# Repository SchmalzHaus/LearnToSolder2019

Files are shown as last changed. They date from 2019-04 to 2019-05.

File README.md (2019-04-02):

# LearnToSolder2018

UNDER CONSTRUCTION - BEING UPDATED

Learn To Solder 2017 Board, assembled

## Introduction

For the past couple years, Deanna Schmalz has designed a simple circuit board which we then use to teach learn to solder classes. We  make enough boards and buy enough parts to teach all of the 4th graders at Glen Lake Elementary School in Minnetonka Minnesota, USA how to solder.

This site contains all of the information related to this year's Learn To Solder board. If you want to learn more about how to solder, if you want to know what you need to purchase so you can solder at home, or if you want to make more of these boards for yourself or your organization, this site has everything you'll need.

If you want to reach Brian Schmalz (brian@schmalzaus.com) or Deanna (deanna@schmalzhaus.com) to ask us any questions, please do so. 

All text files and designs on this site are Open Source. You are free to use these files and do whatever you wish with them.

Bare Board, back and front

## LearnToSolder 2017 Kit Contents

* Qty 1 Bare Circuit Board (see above image for back and front views of the bare board)
* Qty 2 Switches
* Qty 2 Blinking LEDs
* Qty 1 Battery Holder
* Qty 1 Battery

## Tools

To solder electronic kits together, you will need (at a minimum)

### Soldering Iron

We do not recommend buying a soldering iron unless it is 'temperature controlled'. This means you get to set the tip temperature with a knob or buttons, and the iron will only heat up as much as it needs to in order to maintain that temperature. Using a non-temp controlled iron has, in our experience, led to lots of frustration and failed kits.

This is the iron we recommend, as we've had great experience with it and it is very inexpensive : [http://www.hobbyking.com/hobbyking/store/__19240__Soldering_Station_with_Adjustable_Heat_Range_US_Warehouse_.html]

You can also by this same type of iron from many other places, including Amazon and Ebay, but the price tends to be a bit higher. Some of the companies listed below under Other Soldering Kits also sell tools like irons.

### Solder

For beginners, we strongly recommend using leaded solder (rather than lead-free). The safety risk is very minimal (just be sure to wash your hands with soap when you are done) and it is far, far easier to get good soldered joints with leaded solder when you're just starting to learn soldering. You can buy leaded electronic solder at many on-line stores like SparkFun [https://www.sparkfun.com/products/9161] or Adafruit [https://www.adafruit.com/products/1886]. Make sure to buy 60/40 or 63/37 (those numbers represent the ratio of tin to lead in the solder) electronic solder - there are other solders out there (like silver solder for jewelry for example) that won't work for electronics.

### Brass Sponge

When you buy your iron, buy a bras sponge if the iron doesn't already come with it. These are much better than the watter sponge that comes with the iron for cleaning the tip of the soldering iron.

### Wire Cutter

All of the companies listed below sell small wire cutters, or you can get them locally at hardware stores too. The best kind is something that will allow you to cut off wires flush with the board - sometimes called 'flush cutters'. For example [https://www.sparkfun.com/products/11952] or [https://www.adafruit.com/products/152]

### Other tools

There are lots of other tools you can get to help you while solder. Third-hands can be very useful. Needle nose pliers, solder suckers, magnifying glasses, solder wick, wire strippers, etc.

## Kit Assembly Process (overview)

There are only a couple steps to assembling this kit, as it is very simple. If you have done soldering before, you can just walk through this overview of the steps to complete your kit. If you want to learn more about how to do the actual soldering of a joint, the following websites and resources will give you plenty of background materials and explanations:

https://learn.sparkfun.com/tutorials/how-to-solder---through-hole-soldering

http://www.howtogeek.com/63630/how-to-use-a-soldering-iron-a-beginners-guide/

https://cdn-learn.adafruit.com/downloads/pdf/adafruit-guide-excellent-soldering.pdf

### Steps:

1. Insert the two switches into the board. Make sure all parts go into the board from the top side (with the thick white lines) to the back side (with all of the text). The switches snap down into the board - you sometimes have to press them in hard to get them to snap. Solder the four pins of each switch.

2. Insert the two LEDs. Long wires go into square holes. You sometimes have to wiggle the LEDs a bit to get them to press all the way flat down on the top side of the board due to a thick spot on the LED leads. Bend the leads apart on the back side to keep the LEDs in place as you solder the LED wires on the back side of the board.

3. Insert the battery holder to the front of the board, being careful to align the outline of the battery hold to the white outline on the top of the board (there is a square tab on the battery holder than needs to match up to the square tab part of the outline). While holding the battery holder into the board, flip it over and solder both pins.

4. Insert the battery into the holder, flat shiny side up. Press the buttons to see your LEDs light. If you hold down a button, it's LED will begin to cycle through different colors and begin to blink.

You can follow the path of the electricity by looking at the thick white line on the top side of the board, or the thinner copper wires on the back side of the board. (They mirror each other.) 

## Other Soldering Kits

There are SO MANY kits available today, it's impossible to list all of them, or even the good ones. If you do a Google search for "electronic soldering kit" you will find lots of them out there. Some are easier than others, and some come with great instructions (and some don't).

We buy a lot of high quality soldering kits from the following on-line companies:

Evil Mad Scientist [http://shop.evilmadscientist.com/]
* Their Boldport Buggy is excellent [http://shop.evilmadscientist.com/]
* The Flickery Flame is a great beginner kit [http://shop.evilmadscientist.com/productsmenu/793]

Spark Fun Electronics [https://www.sparkfun.com/]
* They have a whole catagory of 'kits', some of which are soldering kits [https://www.sparkfun.com/categories/157]
* The SparkFun Simon Says - Through-Hole kit is really fun [https://www.sparkfun.com/products/10547]

Adafruit [https://www.adafruit.com/]
* The Drawdio is quite fun [https://www.adafruit.com/categories/28]
* Their Minty Boost is actually quite useful [https://www.adafruit.com/products/14]

SeeedStudio [http://www.seeedstudio.com/]
* Their 4-Soldering Zoo Kit looks super cute [https://www.seeedstudio.com/item_detail.html?p_id=1950]

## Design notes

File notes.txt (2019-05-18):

LearnToSolder 2019 Notes file

Build of first rev (v1) of board:
* Thermals too aggressive. Use traces on just one layer instead. (Done)
* Update LED footprint
  - Same sized pads on both top and bottom layers (Done)
  - Separate pads from each other for fewer solder bridges (Done)
* Create cutout for pin 1 dot for processor on tSilk somehow? (Done)
* Update silk on back 
  - larger/thicker text in general (Done)
  - Better build hints (line drawings of LED long lead and battery holder shape) (Done)
* Possibly update silk on front - "Glen Lake"? (Done)

(5/18/2019) V2 of the board was made with all of the above fixed
Blue solder mask

Things to improve for 2020:
* Do not use a ground plane. JLCPCB does not have good enough registration between the solder mask and the copper, so when kids use too much solder, it makes bridges between pins and GND.
* Do not pass out the pliers. They are not needed, and confuse the students.
* Use the document camera to live-demo soldering on the exact board they will solder on. Replace the microscope soldering video witht this.

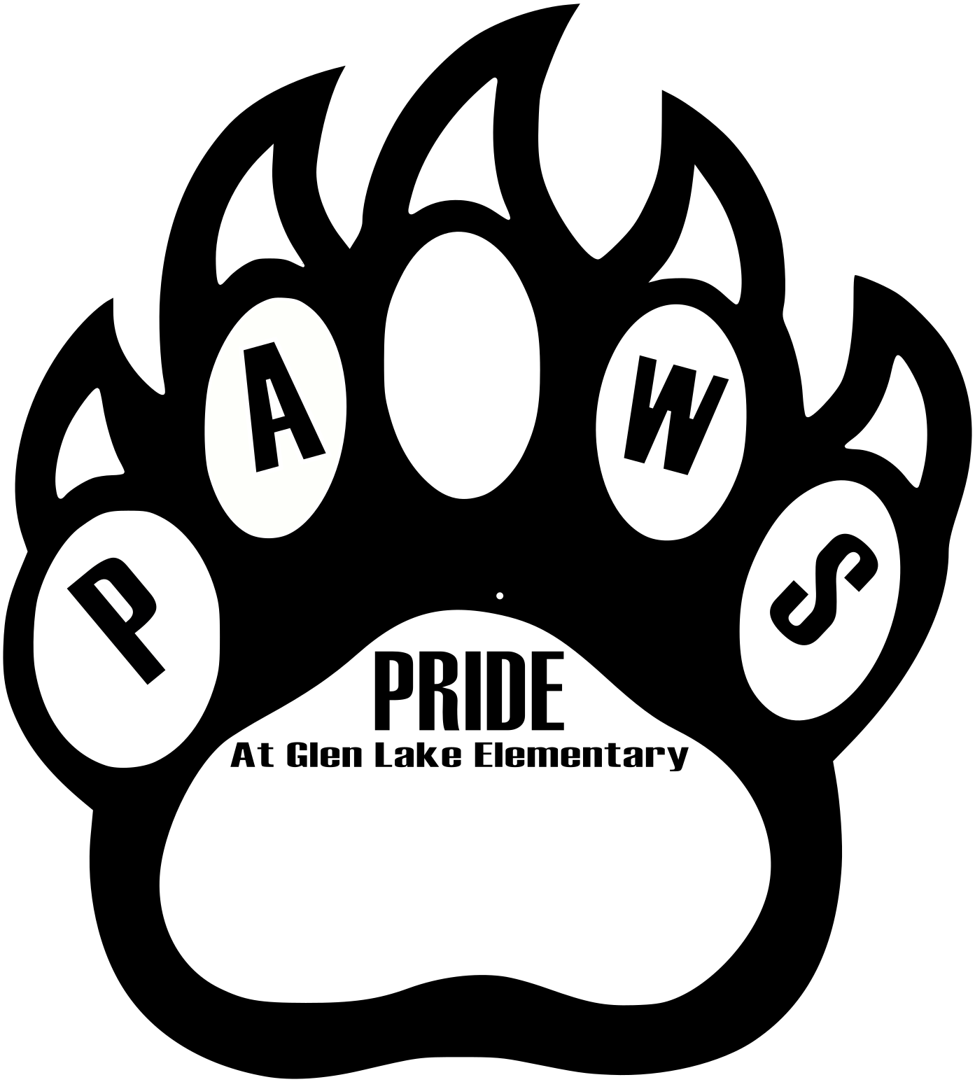
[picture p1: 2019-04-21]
pics/bear-paw-clipart.png

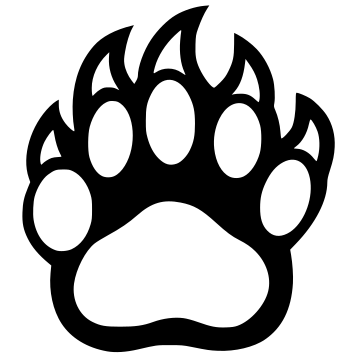
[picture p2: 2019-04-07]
pics/bear-paw-clipart.hi.png

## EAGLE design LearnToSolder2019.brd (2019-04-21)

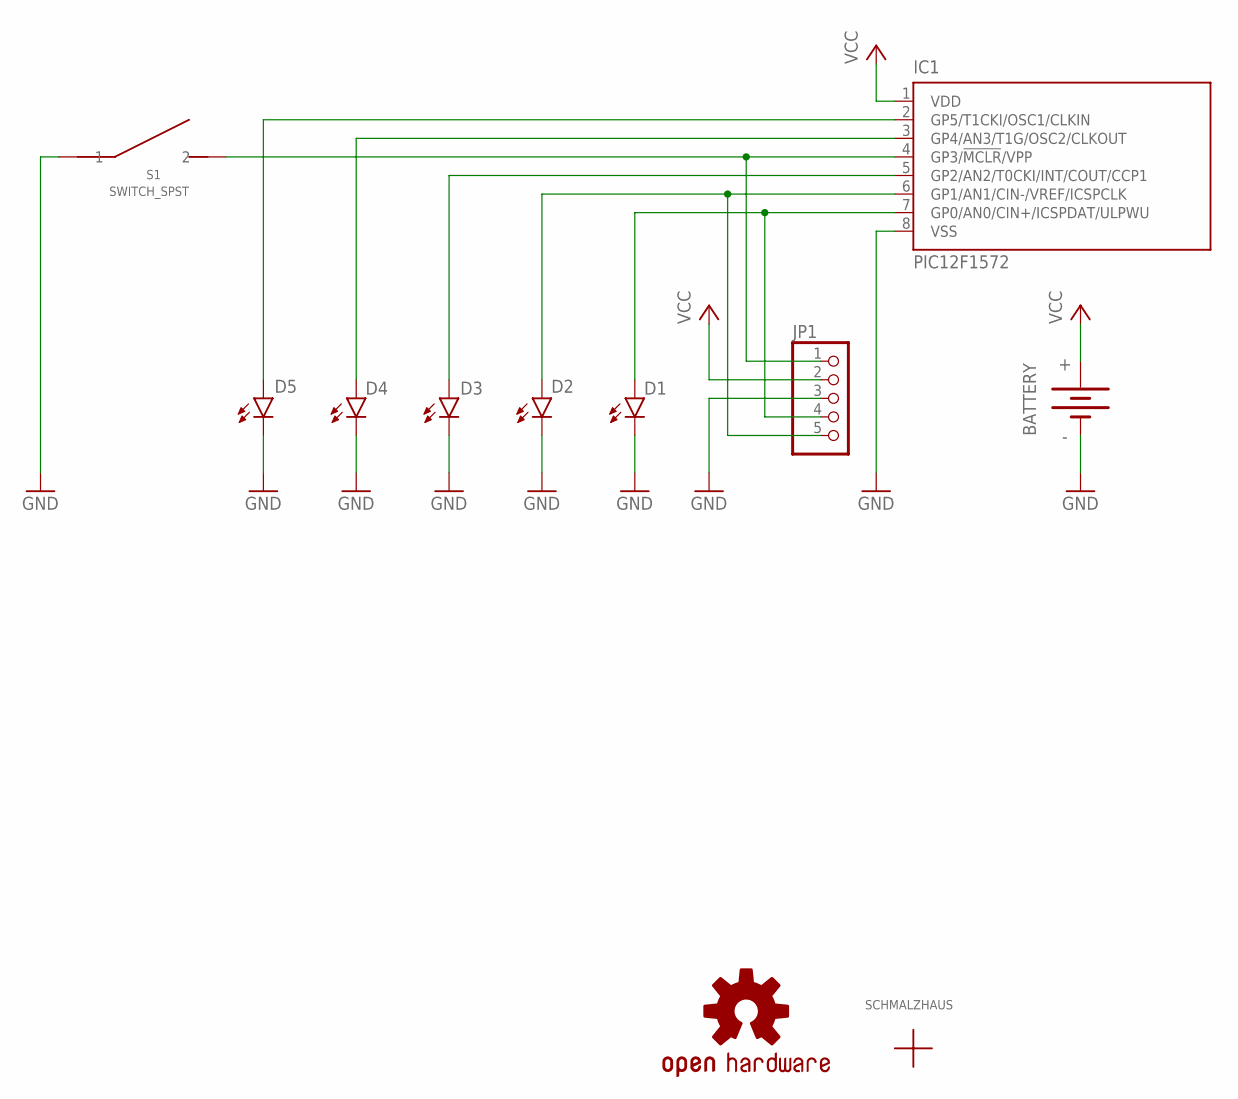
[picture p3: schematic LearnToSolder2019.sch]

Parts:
BATTERY: BATTERY20PTH; BATTCOM_20MM_PTH
D1, D2, D3, D4, D5: LED5MM
IC1: PIC12F1572; SO-08
JP1: PINHD-1X5; 1X05
LOGO1: OSHW-LOGOMINI; OSHW-LOGO-MINI
S1: SWITCH_SPST; OMRON-12MMX12MM_SPST-B3F-4000
U$3: SCHMALZHAUSSCHMALZHAUS_SMALL; SCHMALZHAUS_SMALL

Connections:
GND: BATTERY.2 (-), D1.C, D2.C, D3.C, D4.C, D5.C, IC1.8 (VSS), JP1.3, S1.1, S1.2 (1)
unnamed: IC1.4 (GP3/!MCLR!/VPP), JP1.1, S1.3 (2), S1.4 (2)
unnamed: D4.A, IC1.3 (GP4/AN3/T1G/OSC2/CLKOUT)
unnamed: D3.A, IC1.5 (GP2/AN2/T0CKI/INT/COUT/CCP1)
unnamed: D1.A, IC1.7 (GP0/AN0/CIN+/ICSPDAT/ULPWU), JP1.4
unnamed: D2.A, IC1.6 (GP1/AN1/CIN-/VREF/ICSPCLK), JP1.5
unnamed: D5.A, IC1.2 (GP5/T1CKI/OSC1/CLKIN)
VCC: BATTERY.1 (+), IC1.1 (VDD), JP1.2

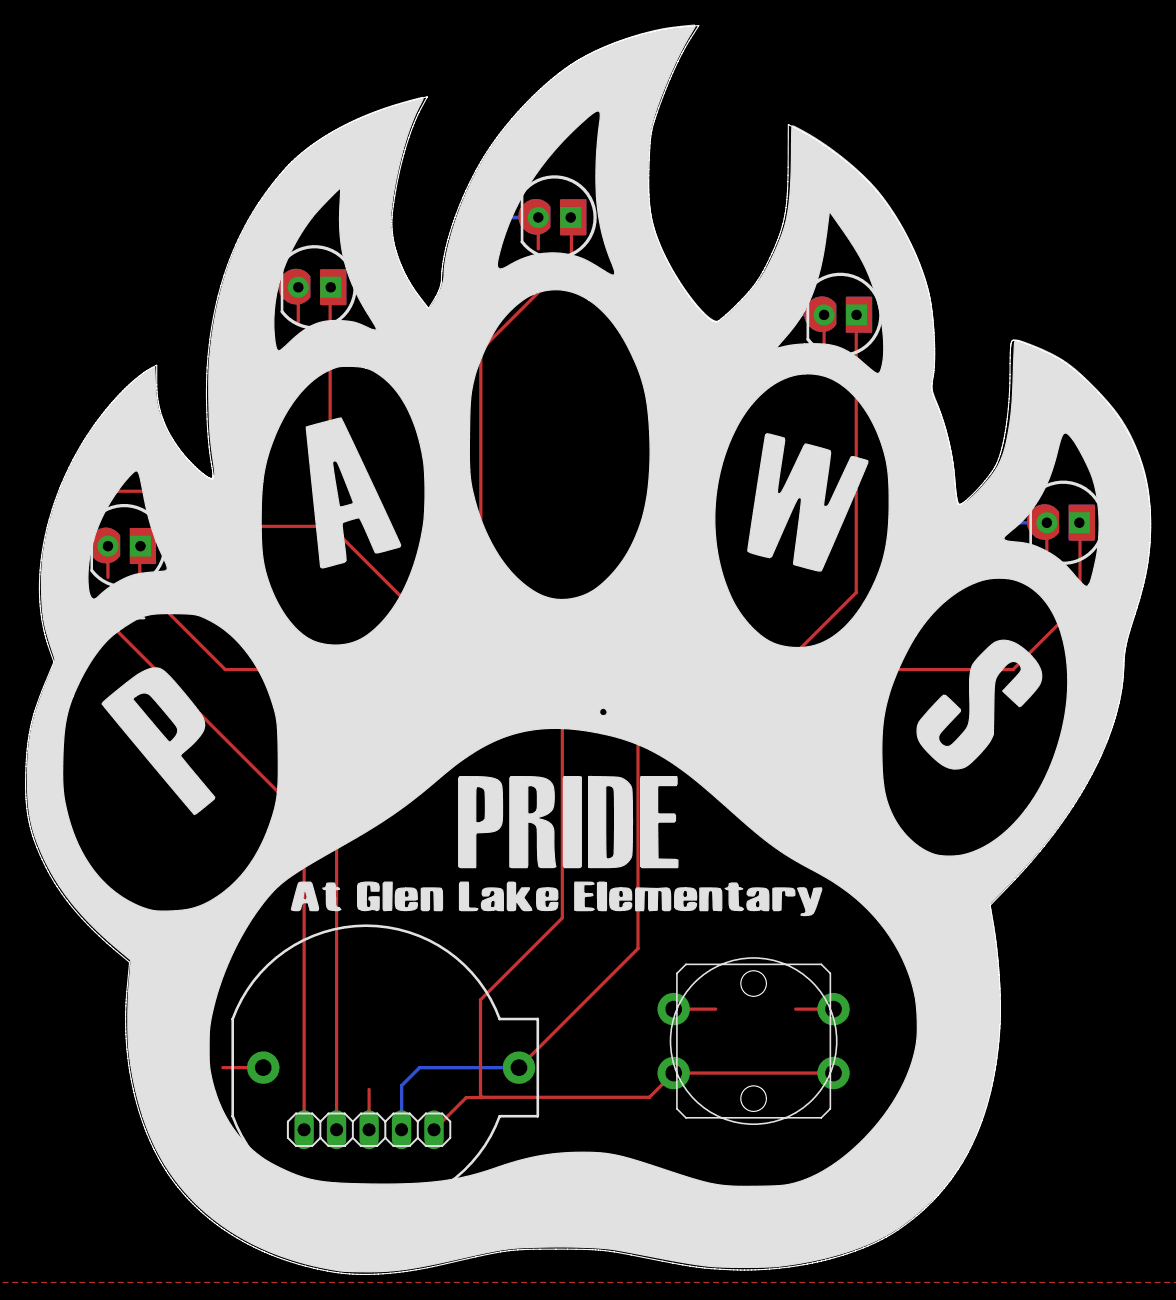
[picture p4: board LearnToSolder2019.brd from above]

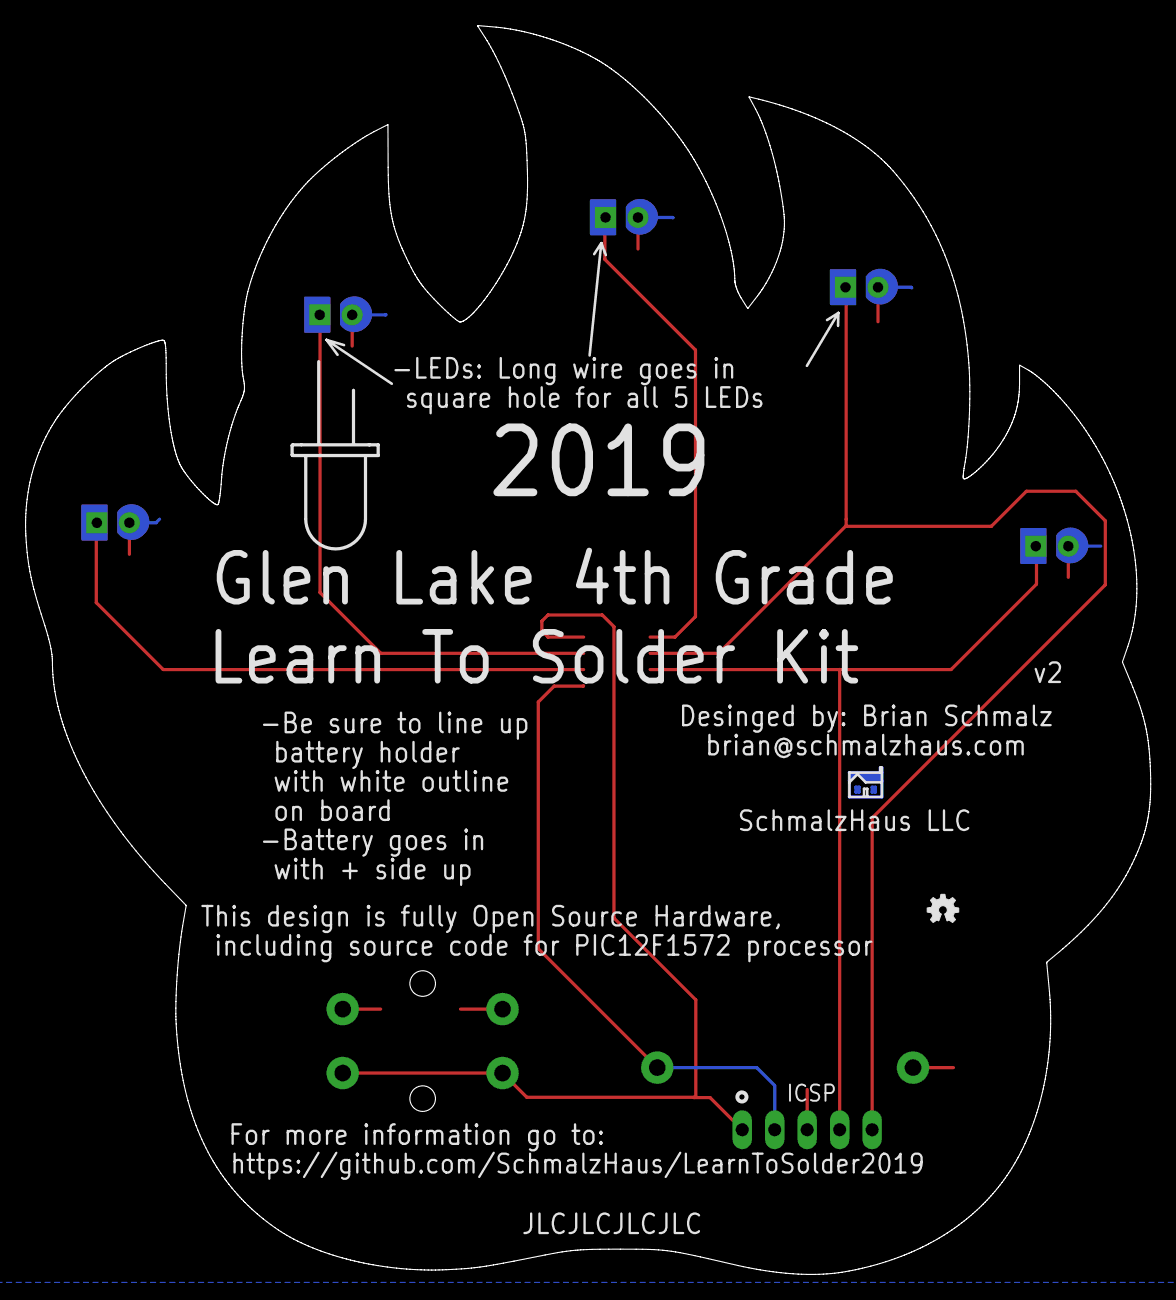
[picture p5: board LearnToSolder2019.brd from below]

Board: 2 copper layers, 88.0 x 97.7 mm, 11 parts (2 on the bottom side), 8 nets.

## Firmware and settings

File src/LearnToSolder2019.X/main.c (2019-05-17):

/*
 * Learn To Solder 2019 board software
 * 
 * Written by Brian Schmalz of Schmalz Haus LLC
 * brian@schmalzhaus.com
 * 
 * Copyright 2019
 * All of this code is in the public domain
 * 
 * Versions:
 * 
 */

#include "mcc_generated_files/mcc.h"

// Button debounce time in milliseconds
#define BUTTON_DEBOUNCE_MS   20

// Number of milliseconds to stay awake for before sleeping just to see if another
// button will be pressed
#define SHUTDOWN_DELAY_MS   100

/* Switch input :  (pressed = low)
 * S1 = GP3
 * 
 * LEDs: (from left to right in claws, high = lit)
 * D1 = GP0 
 * D2 = GP1
 * D3 = GP2
 * D4 = GP4
 * D5 = GP5
 */

// I/O pin that push button is on
#define BUTTON_IO             PORTAbits.RA3

#define TRISA_LEDS_ALL_OUTUPT 0xC8    // 0b11001000
#define PORTA_LEDS_ALL_LOW    0x00

#define D1_ON                 LATAbits.LATA0 = 1;
#define D1_OFF                LATAbits.LATA0 = 0;
#define D2_ON                 LATAbits.LATA1 = 1;
#define D2_OFF                LATAbits.LATA1 = 0;
#define D3_ON                 LATAbits.LATA2 = 1;
#define D3_OFF                LATAbits.LATA2 = 0;
#define D4_ON                 LATAbits.LATA4 = 1;
#define D4_OFF                LATAbits.LATA4 = 0;
#define D5_ON                 LATAbits.LATA5 = 1;
#define D5_OFF                LATAbits.LATA5 = 0;

// Bit positions of each LED within Port A
#define LED_D1                0x01  // A0
#define LED_D2                0x02  // A1
#define LED_D3                0x04  // A2
#define LED_D4                0x10  // A4
#define LED_D5                0x20  // A5

// Maximum number of milliseconds to allow system to run
#define MAX_AWAKE_TIME_MS     (5UL * 60UL * 1000UL)

// The five states a button can be in (for debouncing))
typedef enum {
    BUTTON_STATE_IDLE = 0,
    BUTTON_STATE_PRESSED_TIMING,
    BUTTON_STATE_PRESSED,
    BUTTON_STATE_RELEASED_TIMING,
    BUTTON_STATE_RELEASED
} ButtonState_t;


// Working copy of LED bits to copy directly to LATA in the ISR
static uint8_t LATALEDs;

// LED interface from mainline to ISR: a 0 to 255 brightness value for each LED
static volatile uint8_t LEDBrightness[5];

// Used only in ISR to track where in PWM cycle each LED is
static uint8_t LEDPWMCount[5];

// Counts number of milliseconds we are awake for, and puts us to sleep if 
// we stay awake for too long
volatile static uint32_t WakeTimer;

// Counts down from SHUTDOWN_DELAY_MS after everything is over before we go to sleep
volatile static uint8_t ShutdownDelayTimer;

// Countdown 1ms timers to  debounce the button inputs
volatile static uint8_t DebounceTimer;

// Keep track of the state of each button during debounce
volatile static ButtonState_t ButtonState = BUTTON_STATE_IDLE;

// Record the last value of WakeTimer when the button was pushed
volatile static uint32_t LastButtonPressTime;

volatile static uint16_t NextPatternStepTimer;

static uint8_t PatternState;

static uint16_t PatternSpeed = 0;

void SetAllLEDsOff(void)
{
  uint8_t i;
  
  for (i=0; i < 5; i++)
  {
      LEDBrightness[i] = 0;
  }
}

/* This ISR runs every 125 uS. 
 * It also handles a number of software timer decrementing every 1ms.
 */
void RunTMR0(void)
{
  uint8_t i;
  static uint8_t PWMCounter = 0;
  static uint8_t OneMSCounter = 0;
  static uint8_t LEDBrightnessShadow[5] = {0,0,0,0,0};

  if (PWMCounter == 0)
  {
    LATALEDs = 0xFF;
    for (i=0; i < 5; i++)
    {
      LEDBrightnessShadow[i] = LEDBrightness[i];
    }
  }
  
  // If an LED's brightness matches the counter, then turn the LED off
  if (LEDBrightnessShadow[0] == PWMCounter)
  {
    LATALEDs &= ~LED_D1;
  }
  if (LEDBrightnessShadow[1] == PWMCounter)
  {
    LATALEDs &= ~LED_D2;
  }
  if (LEDBrightnessShadow[2] == PWMCounter)
  {
    LATALEDs &= ~LED_D3;
  }
  if (LEDBrightnessShadow[3] == PWMCounter)
  {
    LATALEDs &= ~LED_D4;
  }
  if (LEDBrightnessShadow[4] == PWMCounter)
  {
    LATALEDs &= ~LED_D5;
  }

  // As a final step, copy over the bits we've set up for the 5 LEDs
  LATA = LATALEDs;
  
  PWMCounter++;
  
  // Check to see if it's time to run the 1ms code
  OneMSCounter++;
  if (OneMSCounter >= TMR0_TICKS_PER_MS)
  {
    // Approximately 1ms has passed since last time OneMSCounter was 0, so
    // perform the 1ms tasks
    OneMSCounter = 0;

    // Always increment wake timer to count this millisecond
    WakeTimer++;

    // Decrement button debounce timers
    if (DebounceTimer)
    {
        DebounceTimer--;
    }

    if (ShutdownDelayTimer)
    {
      ShutdownDelayTimer--;
    }
    
    if (NextPatternStepTimer)
    {
      NextPatternStepTimer--;
    }
  }
}

// Return the raw state of the button input
bool ButtonPressedRaw(void)
{
  return (uint8_t)(BUTTON_IO == 0);
}

// Return the logical (debounced) state of the button
bool ButtonPressed(void)
{
    return (ButtonState == BUTTON_STATE_PRESSED);
}

// Return true if button is currently down
bool CheckForButtonPushes(void)
{  
  // Debounce button press
  if (ButtonPressedRaw())
  {
    if (ButtonState == BUTTON_STATE_PRESSED_TIMING)
    {
      if (DebounceTimer == 0)
      {
        ButtonState = BUTTON_STATE_PRESSED;
      }
    }
    else if (ButtonState != BUTTON_STATE_PRESSED)
    {
      ButtonState = BUTTON_STATE_PRESSED_TIMING;
      DebounceTimer = BUTTON_DEBOUNCE_MS;
    }
  }
  else
  {
    if (ButtonState == BUTTON_STATE_RELEASED_TIMING)
    {
      if (DebounceTimer == 0)
      {
        ButtonState = BUTTON_STATE_RELEASED;
      }
    }
    else if (ButtonState != BUTTON_STATE_RELEASED)
    {
      ButtonState = BUTTON_STATE_RELEASED_TIMING;
      DebounceTimer = BUTTON_DEBOUNCE_MS;
    }
  }
    
  return ((bool)(ButtonPressedRaw()));
}

uint32_t PatternStartTime;

// Trigger the start of an LED pattern
void StartPattern(void)
{
  NextPatternStepTimer = 1;
  PatternState = 1;
  PatternSpeed = 150;
  LEDBrightness[0] = 0;
  LEDBrightness[1] = 0;
  LEDBrightness[2] = 0;
  LEDBrightness[3] = 0;
  LEDBrightness[4] = 0;
}

uint8_t Pattern[8][5] = {
  {50, 0, 0, 0, 1},
  { 0,50, 0, 1, 0},
  { 0, 0,50, 0, 0},
  { 0, 1, 0,50, 0},
  { 1, 0, 0, 0,50},
  { 0, 1, 0,50, 0},
  { 0, 0,50, 0, 0},
  { 0,50, 0, 1, 0}
};

// If an LED pattern is running, do whatever needs to be done to run it
// Return true if pattern is still playing back, false if it's done
bool RunPattern(void)
{
  bool ReturnValue = true;
  uint8_t i;
  static uint8_t BlinkCount = 0;
  
  switch (PatternState)
  {
    case 0:
      // Do nothing, as state zero is "no pattern playing"
      LEDBrightness[0] = 0;
      LEDBrightness[1] = 0;
      LEDBrightness[2] = 0;
      LEDBrightness[3] = 0;
      LEDBrightness[4] = 0;
      ReturnValue = false;
      break;
      
    case 1:
      if (NextPatternStepTimer == 0)
      {
        PatternSpeed = (uint8_t)(((uint16_t)PatternSpeed * (uint16_t)8) / (uint16_t)10);
      }
    case 2:
    case 3:
    case 4:
    case 5:
    case 6:
    case 7:
    case 8:
      if (NextPatternStepTimer == 0)
      {
        NextPatternStepTimer = PatternSpeed;

        for (i=0; i < 5; i++)
        {
          LEDBrightness[i] = Pattern[PatternState-1][i];
        }

        PatternState++;
        if (PatternState >= 9)
        {
          PatternState = 1;
        }

        if (PatternSpeed < 15)
        {
          NextPatternStepTimer = 1;
          PatternState = 9;
          BlinkCount = 0;
        }
      }
      break;
      
    case 9:
      if (NextPatternStepTimer == 0)
      {
        NextPatternStepTimer = 350;
        LEDBrightness[0] = 50;
        LEDBrightness[1] = 0;
        LEDBrightness[2] = 50;
        LEDBrightness[3] = 0;
        LEDBrightness[4] = 50;
        PatternState = 10;
        BlinkCount++;
      }
      break;
      
    case 10:
      if (NextPatternStepTimer == 0)
      {
        NextPatternStepTimer = 350;
        LEDBrightness[0] = 0;
        LEDBrightness[1] = 50;
        LEDBrightness[2] = 0;
        LEDBrightness[3] = 50;
        LEDBrightness[4] = 0;
        PatternState = 9;
        if (BlinkCount >= 4)
        {
          PatternState = 0;
          ReturnValue = false;
          LEDBrightness[0] = 0;
          LEDBrightness[1] = 0;
          LEDBrightness[2] = 0;
          LEDBrightness[3] = 0;
          LEDBrightness[4] = 0;
        }
      }
      break;
            
    default:
      ReturnValue = false;
      break;
  }
  return ReturnValue;
}

/*
                         Main application
 */
void main(void)
{
  static bool PlayingPattern = false;

  // initialize the device
  SYSTEM_Initialize();

  TMR0_SetInterruptHandler(RunTMR0);

  // When using interrupts, you need to set the Global and Peripheral Interrupt Enable bits
  // Use the following macros to:

  // Enable the Global Interrupts
  INTERRUPT_GlobalInterruptEnable();

  // Enable the Peripheral Interrupts
  INTERRUPT_PeripheralInterruptEnable();

  // Disable the Global Interrupts
  //INTERRUPT_GlobalInterruptDisable();

  // Disable the Peripheral Interrupts
  //INTERRUPT_PeripheralInterruptDisable();
    
  /// Are these really needed? Probably not
  TRISA = TRISA_LEDS_ALL_OUTUPT;
  PORTA = PORTA_LEDS_ALL_LOW;
  
  while (1)
  {  
    CheckForButtonPushes();
    PlayingPattern = RunPattern();
    
    // If we're not already playing a pattern, has the user pressed the button?
    if (!PlayingPattern && ButtonPressed())
    {
      PlayingPattern = true;
      StartPattern();
    }

    if (!PlayingPattern && (WakeTimer > MAX_AWAKE_TIME_MS))
    {
      SetAllLEDsOff();
      // Allow off command to percolate to LEDs (maximum 32ms)
      __delay_ms(50);

      // For SHUTDOWN_DELAY_MS, check to see if user has pressed the button just as we're trying to go to sleep
      ShutdownDelayTimer = SHUTDOWN_DELAY_MS;

      while (ShutdownDelayTimer && !CheckForButtonPushes())
      {
      }

      // If the button was not pushed, this timer will be at zero, and it's time to sleep
      if (ShutdownDelayTimer == 0)
      {
          // Hit the VREGPM bit to put us in low power sleep mode
        VREGCONbits.VREGPM = 1;

        SLEEP();

        // Start off with time = 0;
        WakeTimer = 0;
      }
    }
  }
}
/**
 End of File
*/

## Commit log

2019-04-02 First check in of LTS2019 - no outline or code work done yet, readme needs to be updated.
    [LearnToSolder2019.brd, LearnToSolder2019.sch]
2019-04-07 First version (v1) done and set to JLC for test fab
    [LearnToSolder2019.brd, LearnToSolder2019.sch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]
2019-04-13 First test code version working, updated notes from first build.
    [LearnToSolder2019.sch]
2019-04-21 Updated silk screen SVG art to include PAWS Pride text and pin 1 indicator for CPU.
    [LearnToSolder2019.brd]
2019-04-21 v2 of the board done and sent to JLC for quick test fab, in blue
    [LearnToSolder2019.brd, LearnToSolder2019.sch]
2019-05-14 Basic non-blocking pattern code now working. Next step is PWM dimming.
2019-05-16 Fixed a large number of bugs. Implemented pattern array system, PWM working, simple 'wave' pattern now works.
    [main.c]

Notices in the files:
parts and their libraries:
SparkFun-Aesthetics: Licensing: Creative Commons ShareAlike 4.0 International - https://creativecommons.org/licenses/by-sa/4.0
